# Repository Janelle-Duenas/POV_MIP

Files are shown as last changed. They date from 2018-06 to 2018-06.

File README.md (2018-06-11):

# POV_MIP
This project was developed by the UCSD Coordinated Robotics Laboratory

These folders contain all the files for the educational POV Mechanism that is mounted on the MIP.
The SolidWorks files folder is separated into plastic parts, eletromechanical parts and hardware.
Please download all these contents as displayed on the repository to retain the parts references for the main assembly.
The PCB Eagle files folder contains the schematic/board files.
The Code folder contains C files that use TI-RTOS.

For a more detail description of this project please see the following document

AIAA Confrence paper : link TBD

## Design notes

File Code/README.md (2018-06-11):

## Summary

This code has been modified from a samlpe TI code to connect to the custom made PCB,
and control the 16 RGB LEDS. The current example utilizes TI ADC API to get information from a hall sensor and then displays an image of a Pac-Man

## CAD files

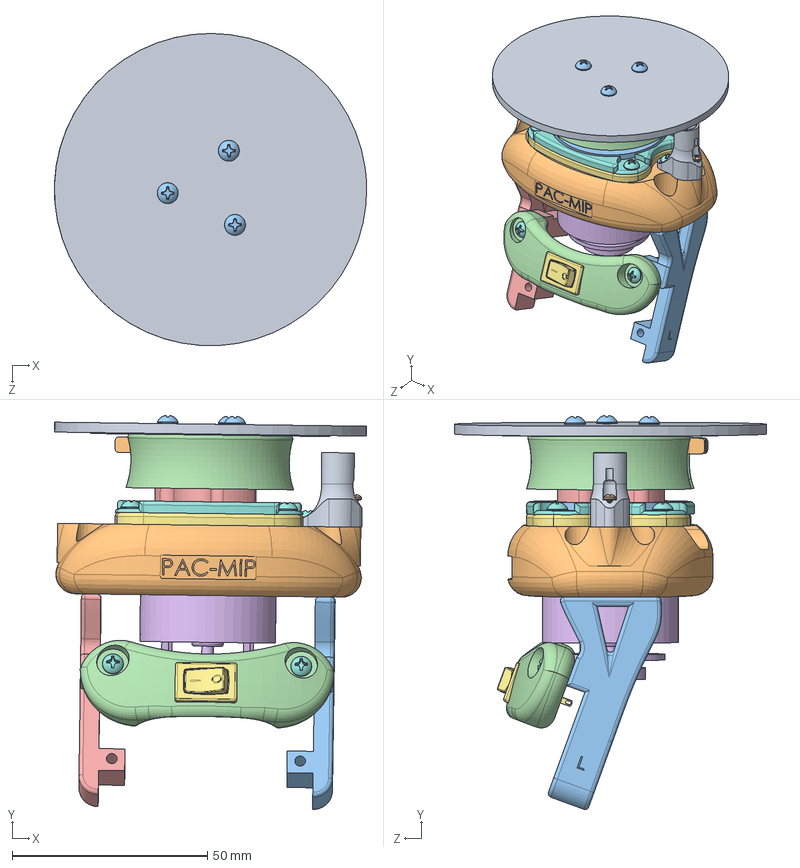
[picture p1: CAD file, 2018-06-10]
SolidWorks files/POV.SLDASM
80.0 x 100.9 x 79.9 mm
PCB disk
Main Frame
Coil x 2
Top Coil Mount
Motor Hub
Motor_pololu-37D-encoder
Motor Mount
Bottom Coil Mount
Magnet Stand
Wire Mount
Left Support
Switch Mount
Right Support
Magnet
Rocker Switch
90279A110_ZNC PLTD STL ROUND HEAD PHILLIP MACHINE SCREW x 7
90279A112_ZNC PLTD STL ROUND HEAD PHILLIP MACHINE SCREW x 4
92000A006_18-8 SS METRIC PAN HEAD PHIL MACHINE SCREW
90279A103_ZNC PLTD STL ROUND HEAD PHILLIP MACHINE SCREW x 3

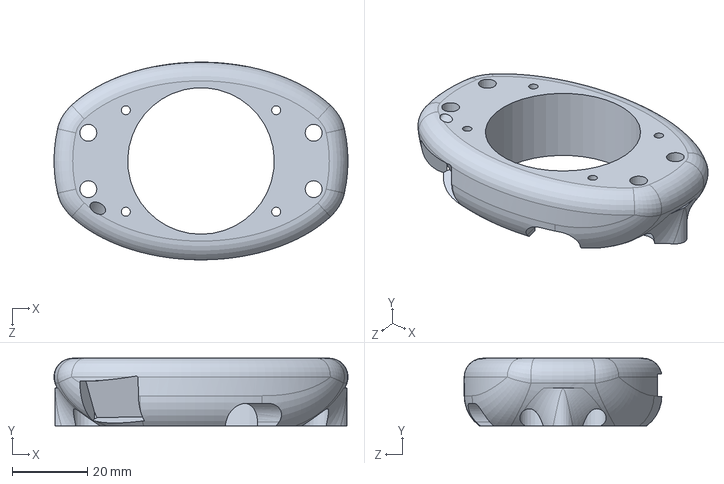
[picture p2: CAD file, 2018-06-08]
SolidWorks files/plastic parts/3D-printed/Main Frame.SLDPRT
78.2 x 18.0 x 52.6 mm

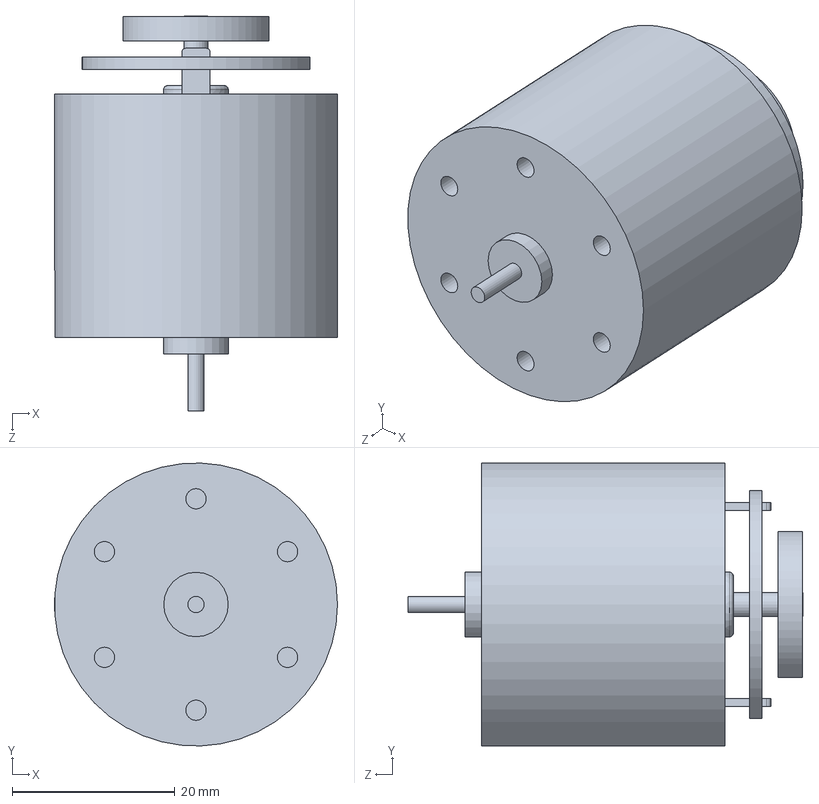
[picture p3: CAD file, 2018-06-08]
SolidWorks files/ElectroMechanical parts/Motor_pololu-37D-encoder.SLDPRT
34.8 x 34.8 x 48.5 mm

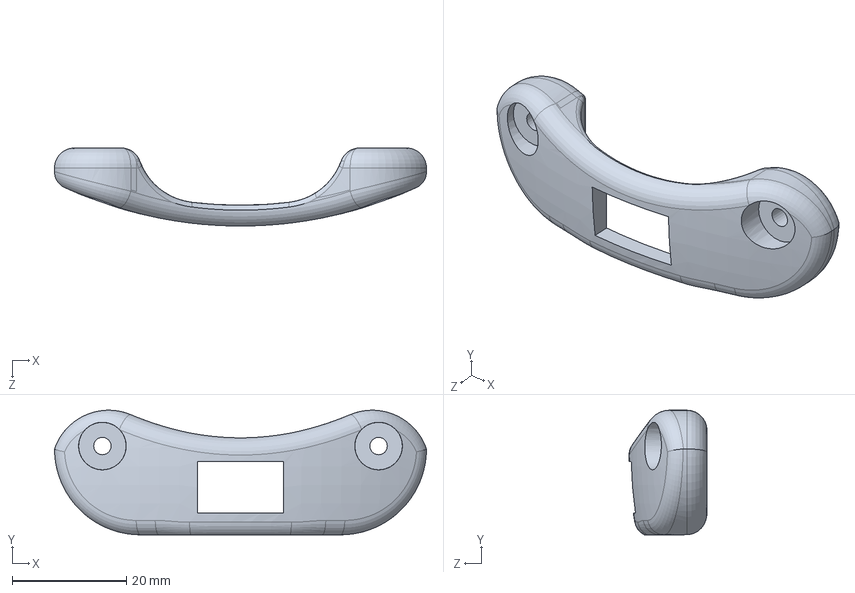
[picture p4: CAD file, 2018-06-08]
SolidWorks files/plastic parts/3D-printed/Switch Mount.SLDPRT
65.0 x 21.8 x 13.6 mm

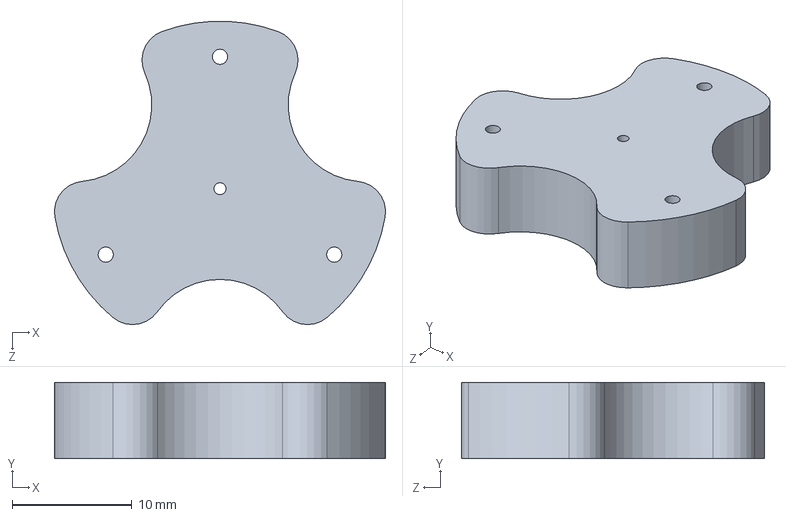
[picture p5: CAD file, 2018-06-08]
SolidWorks files/plastic parts/laser cut/Motor Hub.SLDPRT
27.6 x 6.35 x 25.3 mm

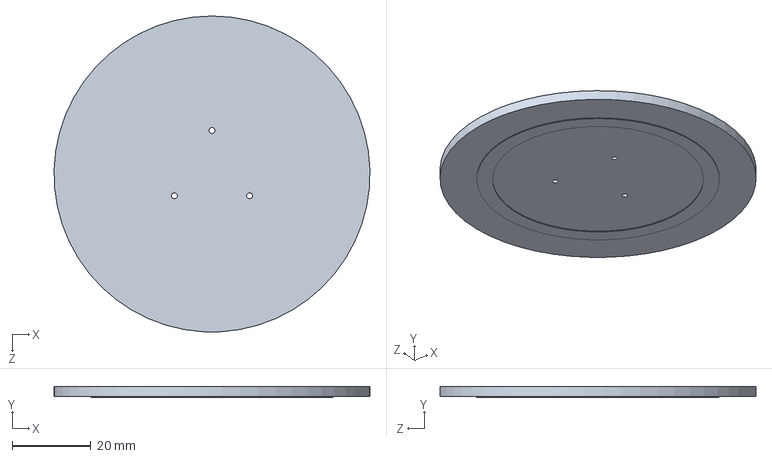
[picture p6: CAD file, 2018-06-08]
SolidWorks files/ElectroMechanical parts/PCB disk.SLDPRT
80.0 x 2.79 x 80.0 mm

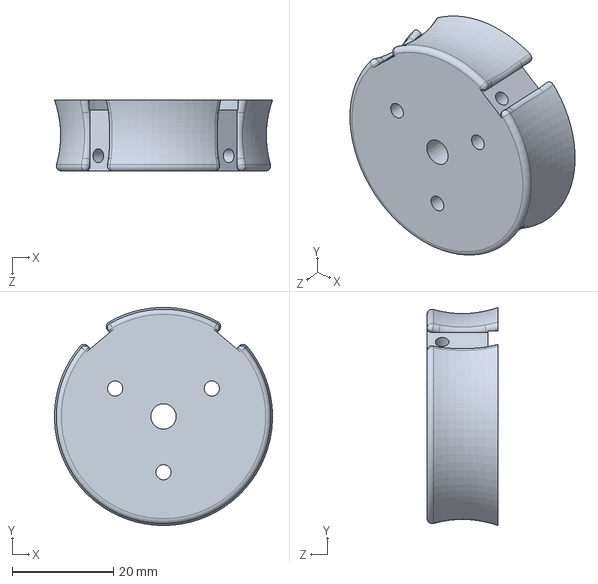
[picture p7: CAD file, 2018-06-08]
SolidWorks files/plastic parts/3D-printed/Top Coil Mount.SLDPRT
43.0 x 43.0 x 14.0 mm

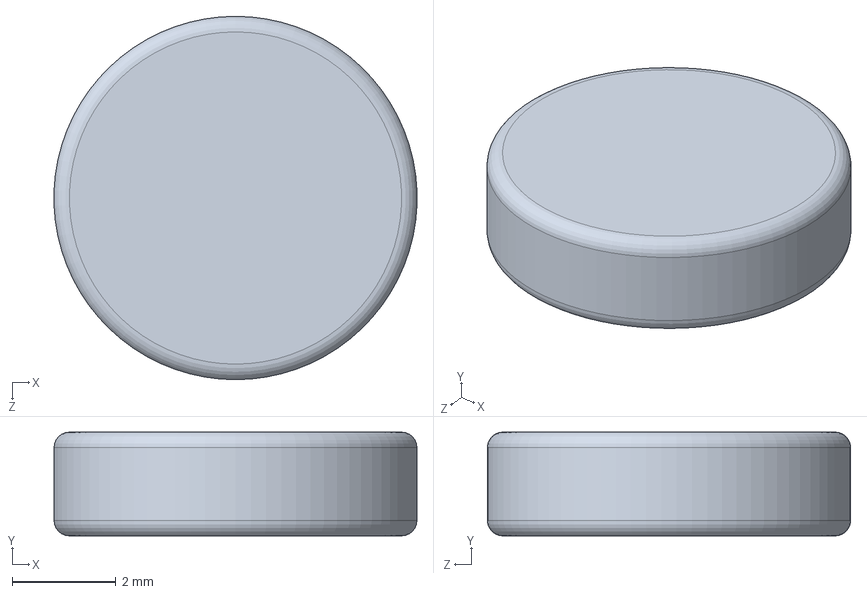
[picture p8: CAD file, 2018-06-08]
SolidWorks files/ElectroMechanical parts/Magnet.SLDPRT
6.99 x 2.00 x 7.00 mm

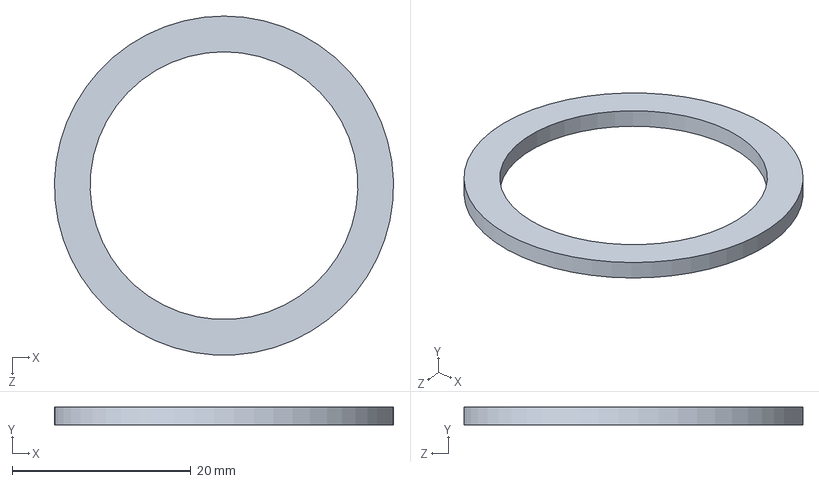
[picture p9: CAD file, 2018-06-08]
SolidWorks files/hardware/Coil.SLDPRT
38.0 x 2.00 x 38.0 mm

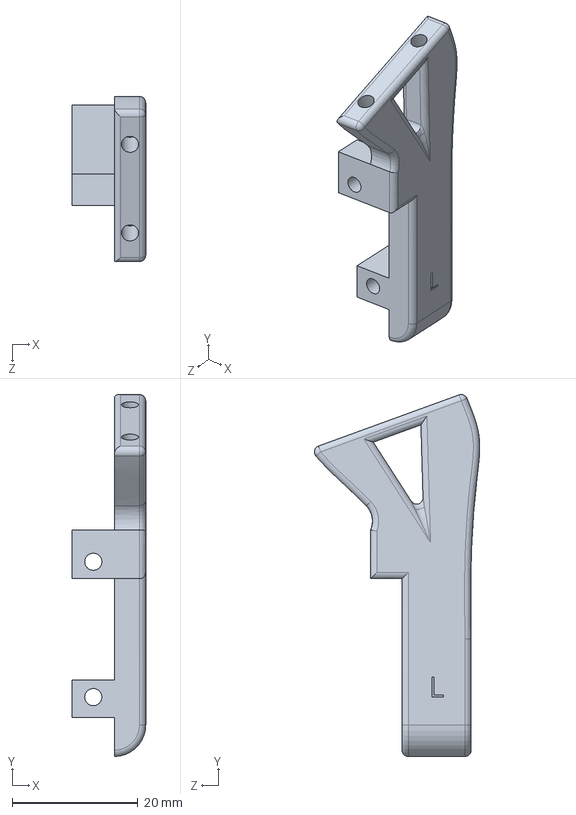
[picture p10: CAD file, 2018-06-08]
SolidWorks files/plastic parts/3D-printed/Left Support.SLDPRT
11.7 x 57.6 x 26.3 mm

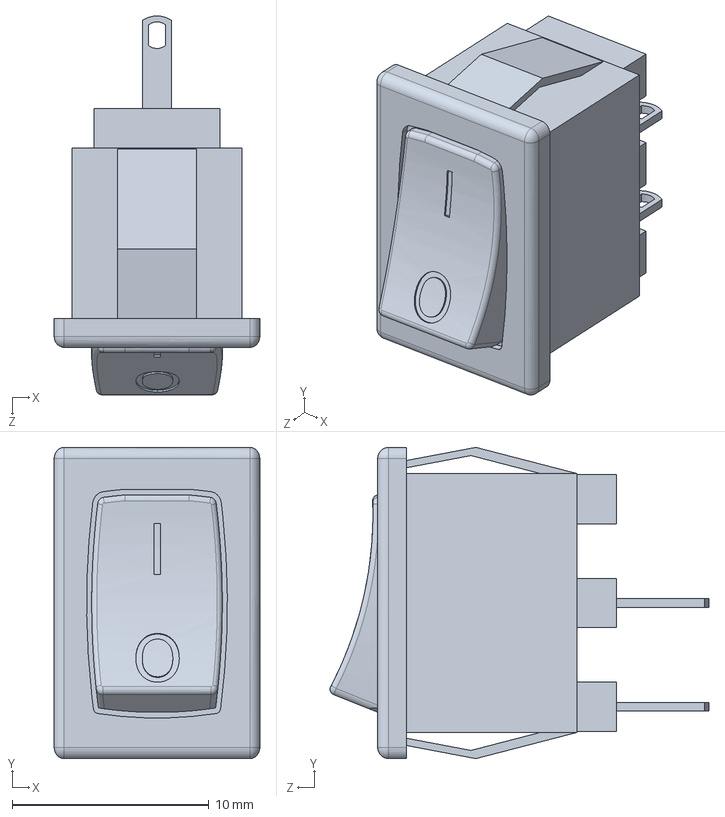
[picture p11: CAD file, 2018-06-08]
SolidWorks files/ElectroMechanical parts/Rocker Switch.SLDPRT
10.5 x 15.8 x 19.3 mm

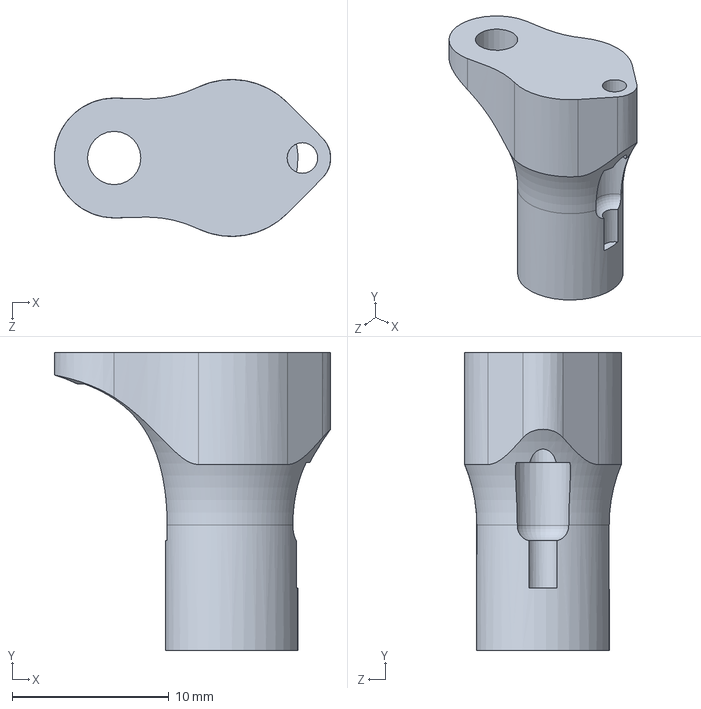
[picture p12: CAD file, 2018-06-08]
SolidWorks files/plastic parts/3D-printed/Magnet Stand.SLDPRT
17.6 x 19.0 x 10.00 mm

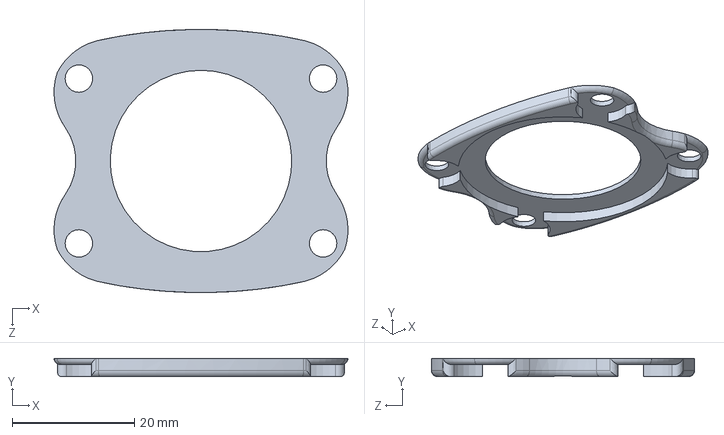
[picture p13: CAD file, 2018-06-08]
SolidWorks files/plastic parts/3D-printed/Bottom Coil Mount.SLDPRT
48.2 x 3.00 x 43.1 mm

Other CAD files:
Code/adcsinglechannel_CC2650_LAUNCHXL_TI_CC2650F128/src/sysbios/m3_TaskSupport_asm.obj
Code/adcsinglechannel_CC2650_LAUNCHXL_TI_CC2650F128/src/sysbios/m3_Hwi_asm.obj
Code/adcsinglechannel_CC2650_LAUNCHXL_TI_CC2650F128/src/sysbios/m3_IntrinsicsSupport_asm.obj
Code/adcsinglechannel_CC2650_LAUNCHXL_TI_CC2650F128/src/sysbios/m3_Hwi_asm_switch.obj
Code/adcsinglechannel_CC2650_LAUNCHXL_TI_CC2650F128/src/sysbios/rom_sysbios.obj
SolidWorks files/hardware/90279A103_ZNC PLTD STL ROUND HEAD PHILLIP MACHINE SCREW.SLDPRT
SolidWorks files/hardware/90279A110_ZNC PLTD STL ROUND HEAD PHILLIP MACHINE SCREW.SLDPRT
SolidWorks files/hardware/90279A112_ZNC PLTD STL ROUND HEAD PHILLIP MACHINE SCREW.SLDPRT
SolidWorks files/hardware/92000A006_18-8 SS METRIC PAN HEAD PHIL MACHINE SCREW.SLDPRT
SolidWorks files/plastic parts/3D-printed/Motor Mount.SLDPRT
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

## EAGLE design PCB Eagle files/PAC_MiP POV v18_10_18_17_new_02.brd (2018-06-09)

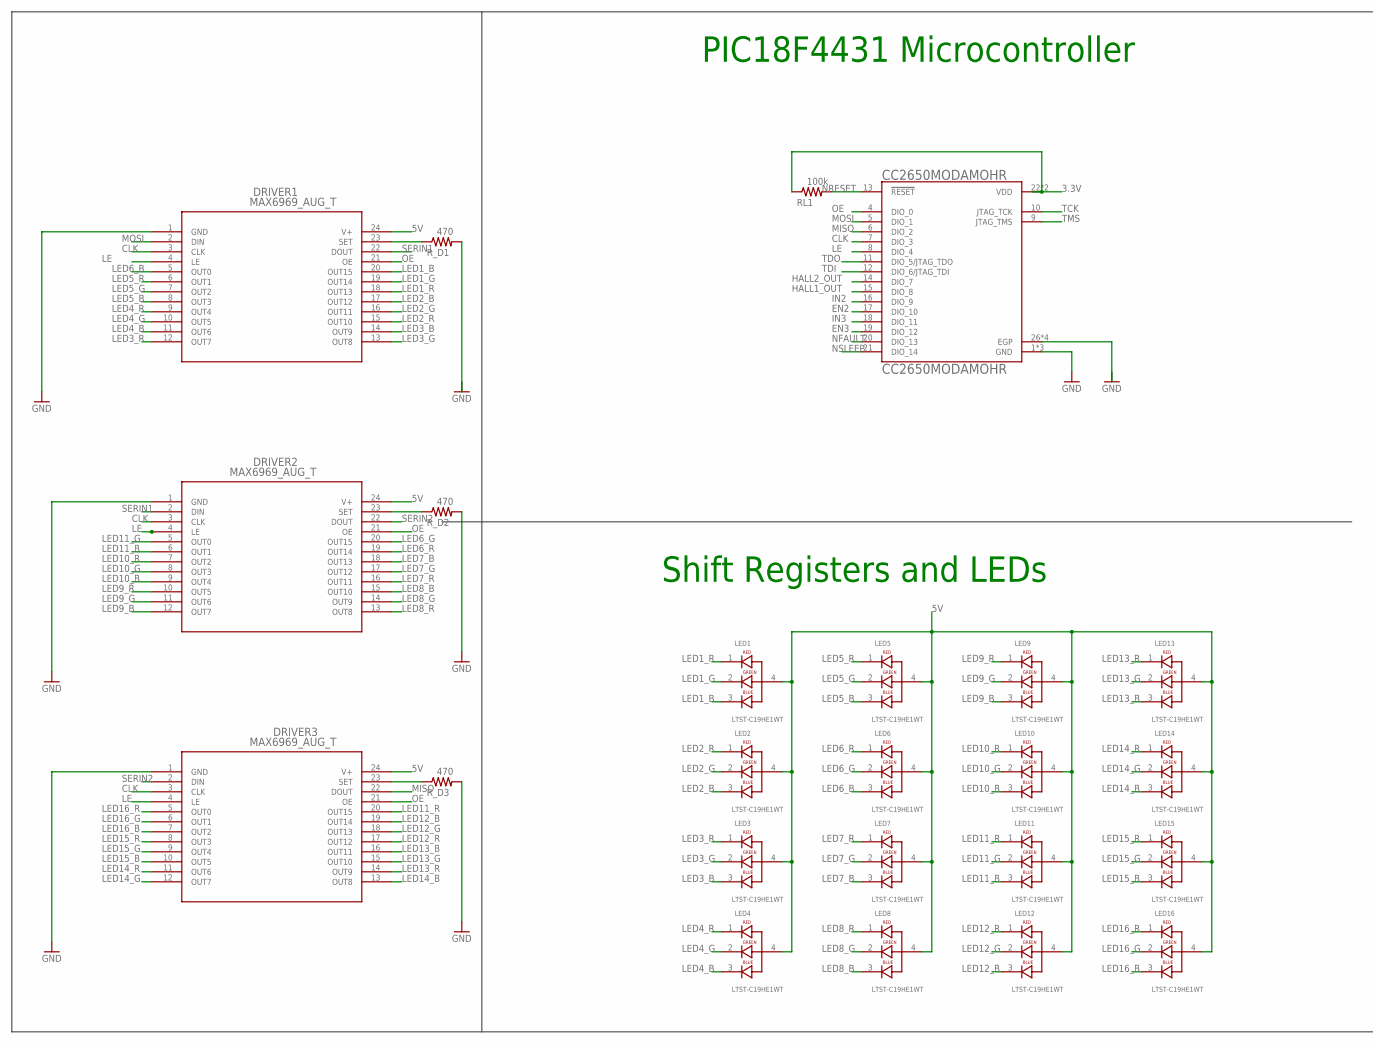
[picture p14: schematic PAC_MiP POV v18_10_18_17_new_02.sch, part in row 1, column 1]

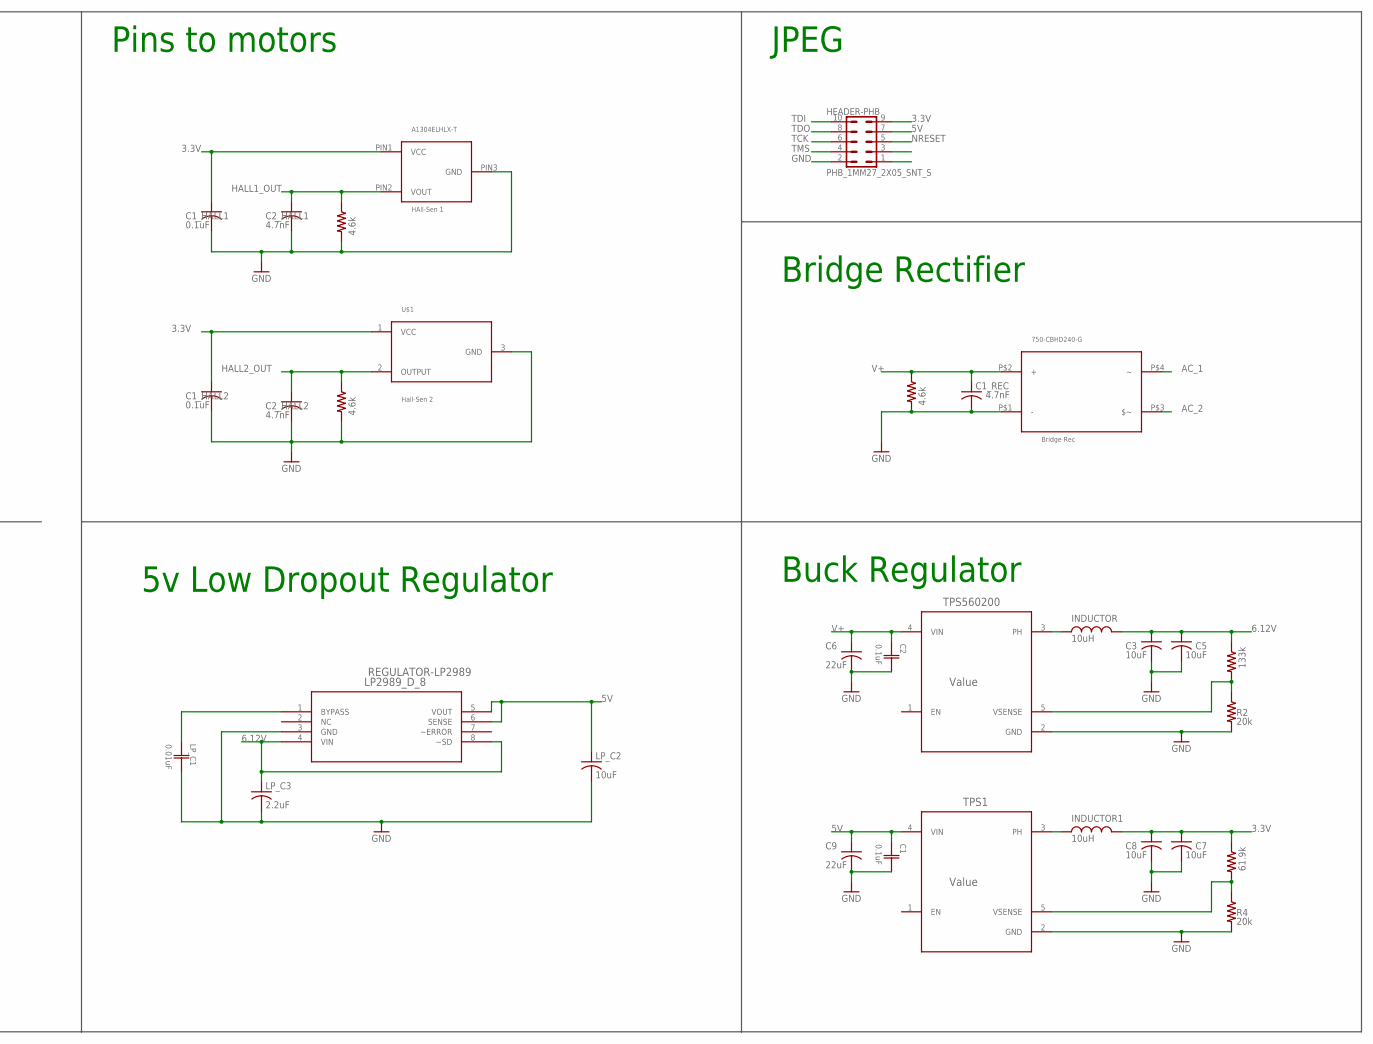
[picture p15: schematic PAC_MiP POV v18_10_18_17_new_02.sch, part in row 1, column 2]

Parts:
750-CBHD240-G: Bridge Rec; 750-CDBHD240-G
A1304ELHLX-T: HAll-Sen 1; A1304ELHLX-T
C1, C2: 0.1uF; 0508
C1_HALL1, C1_HALL2: 0.1uF; C0805
C1_REC, C2_HALL1, C2_HALL2: 4.7nF; C0805
C3, C5, C7, C8: 10uF; C0805
C6, C9: 22uF; C0805
CC2650MODAMOHR: CC2650MODAMOHR; XCVR_CC2650MODAMOHR
DRIVER1, DRIVER2, DRIVER3: MAX6969_AUG_T; 21_0066J_24
HEADER-PHB: PHB_1MM27_2X05_SNT_S; PHB_1MM27_2X05_SNT
INDUCTOR, INDUCTOR1: 10uH; CDPH4D19FNP100MC
LED1, LED2, LED3, LED4, LED5, LED6, LED7, LED8, LED9, LED10, LED11, LED12, LED13, LED14, LED15, LED16: LTST-C19HE1WT; LEDSC85P160X160X35-4N
LP_C1: 0.01uF; LLL18
LP_C2: 10uF; C0805
LP_C3: 2.2uF; C0805
R1: 133k; R0805
R1_HALL, R1_HALL2, R1_REC: 4.6k; R0805
R2, R4: 20k; R0805
R3: 61.9k; R0805
REGULATOR-LP2989: LP2989_D_8; M08A; PARTNUMBER LP2989AIM-18
RL1: 100k; R0805
R_D1, R_D2, R_D3: 470; R0805
TPS1, TPS560200: Value; DBV0005A_N
U$1: Hall-Sen 2; SOT-23-3

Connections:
3.3V: A1304ELHLX-T.PIN1 (VCC), C1_HALL1.1, C1_HALL2.1, C7.1, C8.1, CC2650MODAMOHR.22 (VDD), CC2650MODAMOHR.23 (VDD), HEADER-PHB.9, INDUCTOR1.P$2, R3.1, RL1.1, U$1.1 (VCC)
5V: C1.1, C9.1, DRIVER1.24 (V+), DRIVER2.24 (V+), DRIVER3.24 (V+), HEADER-PHB.7, LED1.4, LED2.4, LED3.4, LED4.4, LED5.4, LED6.4, LED7.4, LED8.4, LED9.4, LED10.4, LED11.4, LED12.4, LED13.4, LED14.4, LED15.4, LED16.4, LP_C2.1, REGULATOR-LP2989.5 (VOUT), REGULATOR-LP2989.6 (SENSE), TPS1.4 (VIN)
6.12V: C3.1, C5.1, INDUCTOR.P$2, LP_C3.1, R1.1, REGULATOR-LP2989.4 (VIN), REGULATOR-LP2989.8 (~SD)
AC_1: 750-CBHD240-G.P$4
AC_2: 750-CBHD240-G.P$3 ($~)
CLK: CC2650MODAMOHR.7 (DIO_3), DRIVER1.3 (CLK), DRIVER2.3 (CLK), DRIVER3.3 (CLK)
EN2: CC2650MODAMOHR.17 (DIO_10)
EN3: CC2650MODAMOHR.19 (DIO_12)
GND: 750-CBHD240-G.P$1 (-), A1304ELHLX-T.PIN3 (GND), C1.2, C1_HALL1.2, C1_HALL2.2, C1_REC.2, C2.2, C2_HALL1.2, C2_HALL2.2, C3.2, C5.2, C6.2, C7.2, C8.2, C9.2, CC2650MODAMOHR.1 (GND), CC2650MODAMOHR.3 (GND), CC2650MODAMOHR.25 (GND), CC2650MODAMOHR.26 (EGP), CC2650MODAMOHR.27 (EGP), CC2650MODAMOHR.28 (EGP), CC2650MODAMOHR.29 (EGP), DRIVER1.1 (GND), DRIVER2.1 (GND), DRIVER3.1 (GND), HEADER-PHB.2, LP_C1.2, LP_C2.2, LP_C3.2, R1_HALL.2, R1_HALL2.2, R1_REC.2, R2.2, R4.2, REGULATOR-LP2989.3 (GND), R_D2.2, R_D3.2, TPS1.2 (GND), TPS560200.2 (GND), U$1.3 (GND)
HALL1_OUT: A1304ELHLX-T.PIN2 (VOUT), C2_HALL1.1, CC2650MODAMOHR.15 (DIO_8), R1_HALL.1
HALL2_OUT: C2_HALL2.1, CC2650MODAMOHR.14 (DIO_7), R1_HALL2.1, U$1.2 (OUTPUT)
IN2: CC2650MODAMOHR.16 (DIO_9)
IN3: CC2650MODAMOHR.18 (DIO_11)
LE: CC2650MODAMOHR.8 (DIO_4), DRIVER1.4 (LE), DRIVER2.4 (LE), DRIVER3.4 (LE)
LED1_B: DRIVER1.20 (OUT15), LED1.3
LED1_G: DRIVER1.19 (OUT14), LED1.2
LED1_R: DRIVER1.18 (OUT13), LED1.1
LED2_B: DRIVER1.17 (OUT12), LED2.3
LED2_G: DRIVER1.16 (OUT11), LED2.2
LED2_R: DRIVER1.15 (OUT10), LED2.1
LED3_B: DRIVER1.14 (OUT9), LED3.3
LED3_G: DRIVER1.13 (OUT8), LED3.2
LED3_R: DRIVER1.12 (OUT7), LED3.1
LED4_B: DRIVER1.11 (OUT6), LED4.3
LED4_G: DRIVER1.10 (OUT5), LED4.2
LED4_R: DRIVER1.9 (OUT4), LED4.1
LED5_B: DRIVER1.8 (OUT3), LED5.3
LED5_G: DRIVER1.7 (OUT2), LED5.2
LED5_R: DRIVER1.6 (OUT1), LED5.1
LED6_B: DRIVER1.5 (OUT0), LED6.3
LED6_G: DRIVER2.20 (OUT15), LED6.2
LED6_R: DRIVER2.19 (OUT14), LED6.1
LED7_B: DRIVER2.18 (OUT13), LED7.3
LED7_G: DRIVER2.17 (OUT12), LED7.2
LED7_R: DRIVER2.16 (OUT11), LED7.1
LED8_B: DRIVER2.15 (OUT10), LED8.3
LED8_G: DRIVER2.14 (OUT9), LED8.2
LED8_R: DRIVER2.13 (OUT8), LED8.1
LED9_B: DRIVER2.12 (OUT7), LED9.3
LED9_G: DRIVER2.11 (OUT6), LED9.2
LED9_R: DRIVER2.10 (OUT5), LED9.1
LED10_B: DRIVER2.9 (OUT4), LED10.3
LED10_G: DRIVER2.8 (OUT3), LED10.2
LED10_R: DRIVER2.7 (OUT2), LED10.1
LED11_B: DRIVER2.6 (OUT1), LED11.3
LED11_G: DRIVER2.5 (OUT0), LED11.2
LED11_R: DRIVER3.20 (OUT15), LED11.1
LED12_B: DRIVER3.19 (OUT14), LED12.3
LED12_G: DRIVER3.18 (OUT13), LED12.2
LED12_R: DRIVER3.17 (OUT12), LED12.1
LED13_B: DRIVER3.16 (OUT11), LED13.3
LED13_G: DRIVER3.15 (OUT10), LED13.2
LED13_R: DRIVER3.14 (OUT9), LED13.1
LED14_B: DRIVER3.13 (OUT8), LED14.3
LED14_G: DRIVER3.12 (OUT7), LED14.2
LED14_R: DRIVER3.11 (OUT6), LED14.1
LED15_B: DRIVER3.10 (OUT5), LED15.3
LED15_G: DRIVER3.9 (OUT4), LED15.2
LED15_R: DRIVER3.8 (OUT3), LED15.1
LED16_B: DRIVER3.7 (OUT2), LED16.3
LED16_G: DRIVER3.6 (OUT1), LED16.2
LED16_R: DRIVER3.5 (OUT0), LED16.1
MISO: CC2650MODAMOHR.6 (DIO_2), DRIVER3.22 (DOUT)
MOSI: CC2650MODAMOHR.5 (DIO_1), DRIVER1.2 (DIN)
unnamed: INDUCTOR.P$1, TPS560200.3 (PH)
unnamed: DRIVER3.23 (SET), R_D3.1
unnamed: R1.2, R2.1, TPS560200.5 (VSENSE)
unnamed: R3.2, R4.1, TPS1.5 (VSENSE)
unnamed: INDUCTOR1.P$1, TPS1.3 (PH)
unnamed: DRIVER2.23 (SET), R_D2.1
unnamed: DRIVER1.23 (SET), R_D1.1
unnamed: LP_C1.1, REGULATOR-LP2989.1 (BYPASS)
NFAULT: CC2650MODAMOHR.20 (DIO_13)
NRESET: CC2650MODAMOHR.13 (!RESET), HEADER-PHB.5, RL1.2
NSLEEP: CC2650MODAMOHR.21 (DIO_14)
OE: CC2650MODAMOHR.4 (DIO_0), DRIVER1.21 (OE), DRIVER2.21 (OE), DRIVER3.21 (OE)
SERIN1: DRIVER1.22 (DOUT), DRIVER2.2 (DIN)
SERIN2: DRIVER2.22 (DOUT), DRIVER3.2 (DIN)
TCK: CC2650MODAMOHR.10 (JTAG_TCK), HEADER-PHB.6
TDI: CC2650MODAMOHR.12 (DIO_6/JTAG_TDI), HEADER-PHB.10
TDO: CC2650MODAMOHR.11 (DIO_5/JTAG_TDO), HEADER-PHB.8
TMS: CC2650MODAMOHR.9 (JTAG_TMS), HEADER-PHB.4
V+: 750-CBHD240-G.P$2 (+), C1_REC.1, C2.1, C6.1, R1_REC.1, TPS560200.4 (VIN)

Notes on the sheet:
Pins to motors
Buck Regulator
Bridge Rectifier
PIC18F4431 Microcontroller
JPEG
Shift Registers and LEDs
5v Low Dropout Regulator

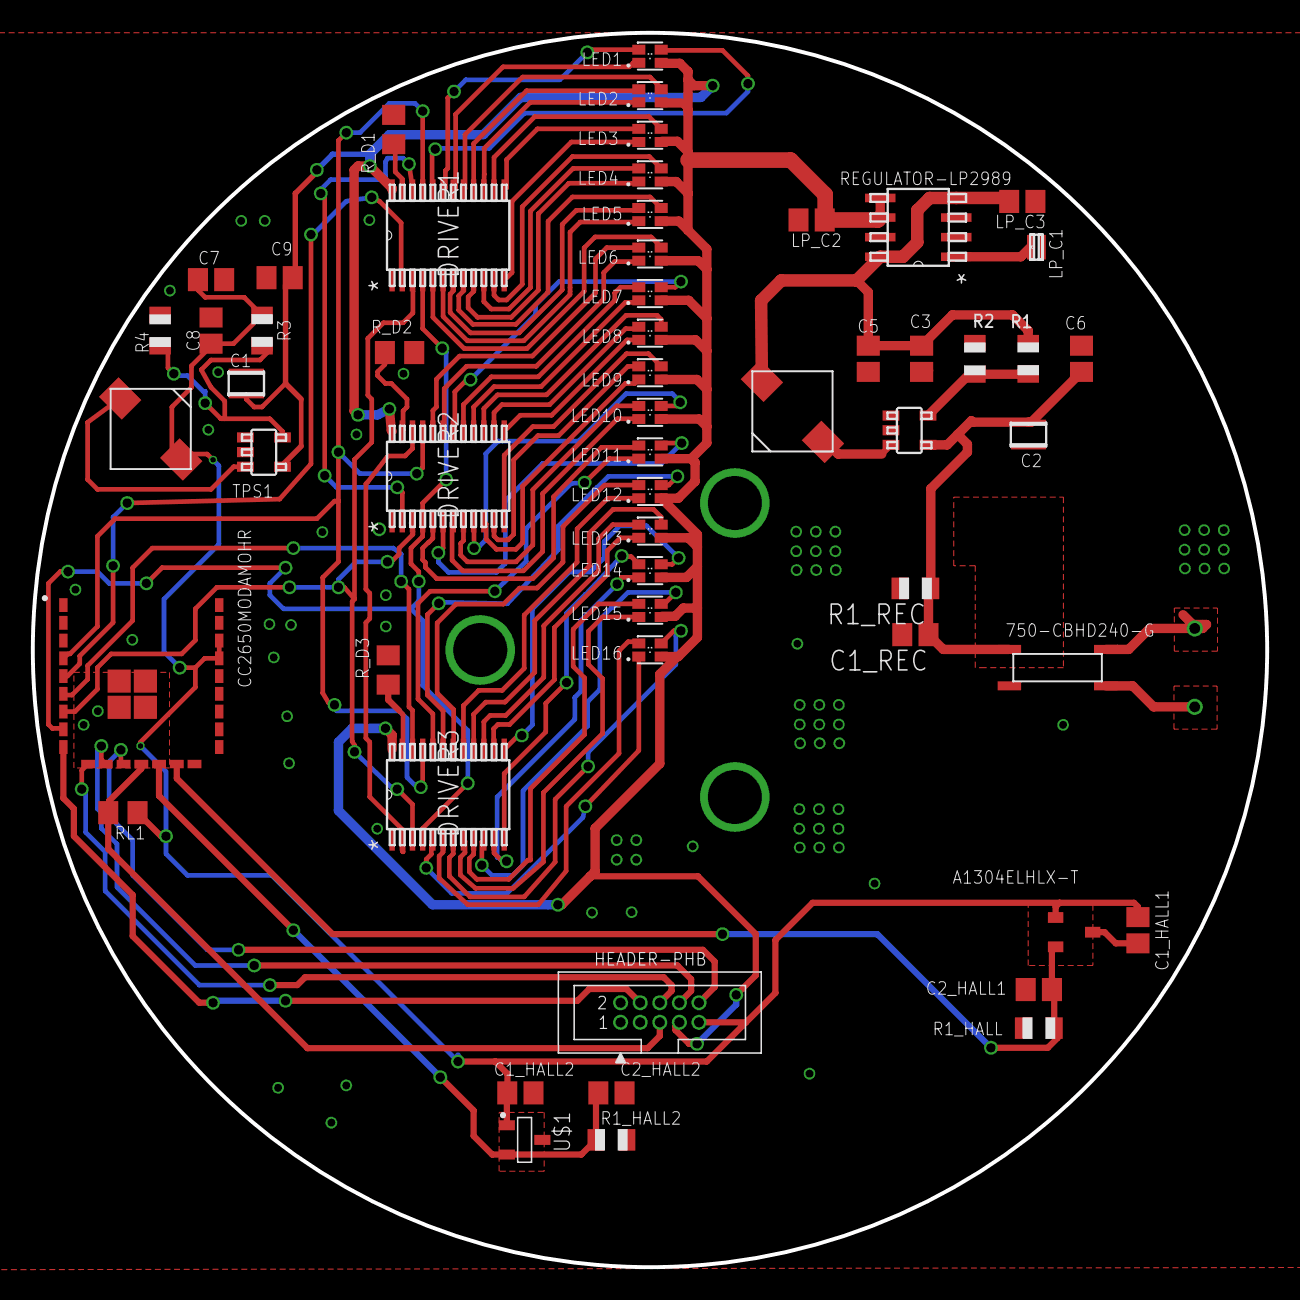
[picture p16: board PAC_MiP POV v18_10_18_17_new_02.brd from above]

Board: 4 copper layers, 80.0 x 80.0 mm, 56 parts (0 on the bottom side), 75 nets.

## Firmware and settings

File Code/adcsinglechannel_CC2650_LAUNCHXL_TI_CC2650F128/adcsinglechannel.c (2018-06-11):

/*
 * Copyright (c) 2016, Texas Instruments Incorporated
 * All rights reserved.
 *
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
 * *  Redistributions of source code must retain the above copyright
 *    notice, this list of conditions and the following disclaimer.
 *
 * *  Redistributions in binary form must reproduce the above copyright
 *    notice, this list of conditions and the following disclaimer in the
 *    documentation and/or other materials provided with the distribution.
 *
 * *  Neither the name of Texas Instruments Incorporated nor the names of
 *    its contributors may be used to endorse or promote products derived
 *    from this software without specific prior written permission.
 *
 * THIS SOFTWARE IS PROVIDED BY THE COPYRIGHT HOLDERS AND CONTRIBUTORS "AS IS"
 * AND ANY EXPRESS OR IMPLIED WARRANTIES, INCLUDING, BUT NOT LIMITED TO,
 * THE IMPLIED WARRANTIES OF MERCHANTABILITY AND FITNESS FOR A PARTICULAR
 * PURPOSE ARE DISCLAIMED. IN NO EVENT SHALL THE COPYRIGHT OWNER OR
 * CONTRIBUTORS BE LIABLE FOR ANY DIRECT, INDIRECT, INCIDENTAL, SPECIAL,
 * EXEMPLARY, OR CONSEQUENTIAL DAMAGES (INCLUDING, BUT NOT LIMITED TO,
 * PROCUREMENT OF SUBSTITUTE GOODS OR SERVICES; LOSS OF USE, DATA, OR PROFITS;
 * OR BUSINESS INTERRUPTION) HOWEVER CAUSED AND ON ANY THEORY OF LIABILITY,
 * WHETHER IN CONTRACT, STRICT LIABILITY, OR TORT (INCLUDING NEGLIGENCE OR
 * OTHERWISE) ARISING IN ANY WAY OUT OF THE USE OF THIS SOFTWARE,
 * EVEN IF ADVISED OF THE POSSIBILITY OF SUCH DAMAGE.
 */

/*
 * %%%%%%%%%%%%%%%%%%%%%%%%%%%%%%%%%%%%%%%%%%%%%%%%%%%%%%%%%%%%%%%%%%%%%%%%%%%%%%%%%%%%%%%%%%%%%%%%%%%%%%%%%%%%
 * * READ ME!
 *
 * This code has been modified from TI adcsinglechannel_CC2650_LAUNCH_TI_CC2650F128
 * although the name has been kept to be the side, for comparison, this code connects to the
 * PCB created by the Coordinated Robotics Laboratory found at the link https://github.com/Janelle-Duenas/POV_MIP
 * The current code will display a PacMan
 *
 * %%%%%%%%%%%%%%%%%%%%%%%%%%%%%%%%%%%%%%%%%%%%%%%%%%%%%%%%%%%%%%%%%%%%%%%%%%%%%%%%%%%%%%%%%%%%%%%%%%%%%%%%%%%%%%

 */


/*
 *  ======== adcsinglechannel.c ========
 */
/* XDCtools Header files*/
#include <stdio.h>
#include <xdc/std.h>
#include <xdc/runtime/System.h>

//uses this for usleep
//#include <unistd.h>

/* BIOS Header files */
#include <ti/sysbios/BIOS.h>
#include <ti/sysbios/knl/Task.h>

/* Driver Header files */
#include <ti/drivers/ADC.h>
#include <ti/drivers/PIN.h>
#include <time.h>

#include <ti/drivers/pin/PINCC26XX.h>///janelle added this
#if defined(CC2650DK_7ID) || defined(CC1310DK_7XD)
#include <ti/drivers/PIN.h>

#include <ti/drivers/pin/PINCC26XX.h>///janelle added this
#endif

volatile uint32_t i,j;

/*
 *  ======== Pin set-up ========
 */

PIN_Config ledPinTable[] = {

    IOID_0 | PIN_GPIO_OUTPUT_EN | PIN_GPIO_LOW | PIN_PUSHPULL | PIN_DRVSTR_MAX,        //OE
    IOID_1 | PIN_GPIO_OUTPUT_EN | PIN_GPIO_LOW | PIN_PUSHPULL | PIN_DRVSTR_MAX,        //MOSI(DIN)
    IOID_3 | PIN_GPIO_OUTPUT_EN | PIN_GPIO_LOW | PIN_PUSHPULL | PIN_DRVSTR_MAX,        //CLK
    IOID_4 | PIN_GPIO_OUTPUT_EN | PIN_GPIO_HIGH | PIN_PUSHPULL | PIN_DRVSTR_MAX,        //LE


   // IOID_7 | PIN_GPIO_OUTPUT_EN | PIN_GPIO_LOW | PIN_PUSHPULL | PIN_DRVSTR_MAX,        //IN1
   // IOID_8 | PIN_GPIO_OUTPUT_EN | PIN_GPIO_LOW | PIN_PUSHPULL | PIN_DRVSTR_MAX,        //EN1
    IOID_9 | PIN_GPIO_OUTPUT_EN | PIN_GPIO_LOW | PIN_PUSHPULL | PIN_DRVSTR_MAX,        //IN2
    IOID_10 | PIN_GPIO_OUTPUT_EN | PIN_GPIO_LOW | PIN_PUSHPULL | PIN_DRVSTR_MAX,       //EN2
    IOID_11 | PIN_GPIO_OUTPUT_EN | PIN_GPIO_LOW | PIN_PUSHPULL | PIN_DRVSTR_MAX,        //IN3
    IOID_12 | PIN_GPIO_OUTPUT_EN | PIN_GPIO_LOW | PIN_PUSHPULL | PIN_DRVSTR_MAX,        //EN3
    IOID_14 | PIN_GPIO_OUTPUT_EN | PIN_GPIO_LOW | PIN_PUSHPULL | PIN_DRVSTR_MAX,        //nsleep
    ///IOID_7 | PIN_INPUT_EN | PIN_PULLDOWN,  //analog pin
    ///IOID_8 | PIN_INPUT_EN | PIN_PULLDOWN,  //analog pin

    PIN_TERMINATE

};


static PIN_Handle ledPinHandle;
static PIN_State ledPinState;




/* Example/Board Header files */
#include "Board.h"

/* ADC sample count */
#define ADC_SAMPLE_COUNT  (300)

/*Task Specific defines */
#define TASKSTACKSIZE     (768)

Task_Struct task0Struct;
Char task0Stack[TASKSTACKSIZE];

Task_Struct task1Struct;
Char task1Stack[TASKSTACKSIZE];

/* ADC conversion result variables */
uint16_t adcValue0;
uint16_t adcValue_current;
uint16_t adcValue1[ADC_SAMPLE_COUNT];
//double adcValue1[ADC_SAMPLE_COUNT];
double Time[ADC_SAMPLE_COUNT];
    int r=3;
/*
 *  ======== taskFxn0 ========
 *  Open an ADC instance and get a sampling result from a one-shot conversion.
 */
Void taskFxn0(UArg arg0, UArg arg1)
{
    ADC_Handle   adc;
    ADC_Params   params;
    int_fast16_t res;

    ADC_Params_init(&params);
    adc = ADC_open(Board_ADC0, &params);

    if (adc == NULL) {
        System_abort("Error initializing ADC channel 0\n");
    }
    else {
       // System_printf("ADC channel 0 initialized\n");
    }

    /* Blocking mode conversion */
    res = ADC_convert(adc, &adcValue0);

    if (res == ADC_STATUS_SUCCESS) {
       System_printf("ADC channel 0 convert result: 0x%x\n", adcValue0);
    }
    else {
        System_printf("ADC channel 0 convert failed\n");
    }

    ADC_close(adc);


    System_flush();
}

/*
 *  ======== taskFxn1 ========
 *  Open a ADC handle and get a array of sampling results after
 *  calling several conversions.
 */
Void taskFxn1(UArg arg0, UArg arg1)
{
    uint16_t     i=0;
    ADC_Handle   adc;
    ADC_Params   params;
    int_fast16_t res;

    ADC_Params_init(&params);
    adc = ADC_open(Board_ADC0, &params);

    if (adc == NULL) {
        System_abort("Error initializing ADC channel 1\n");
    }
    else {
      //  System_printf("ADC channel 1 initialized\n");
    }
////////////////////////////////////////////////////////////////////////////
   /*for (i = 0; i < ADC_SAMPLE_COUNT; i++) {
     //while(true){
        //res = ADC_convert(adc, &adcValue1[i]);
       res = ADC_convert(adc, &adcValue_current);

       if(1<ADC_SAMPLE_COUNT){
       adcValue1[i]=adcValue_current;
       time_t x=time(0);
        Time[i]=x;
       }
        //adcValue1[i]=hextoint(adcValue1[i]);

        if (res == ADC_STATUS_SUCCESS) {

        //  System_printf("ADC channel 1 convert result (%d): %d\n", i,//0x%x
           // adcValue1[i]);
        }
        else {
           // System_printf("ADC channel 1 convert failed (%d)\n", i);
            System_printf("ADC channel 1 convert failed\n");
        }

        if(adcValue_current>2250){//hexacecimal for 2250 or 2.25 V
           PIN_setOutputValue(ledPinHandle, IOID_0, Board_LED_OFF );    //OE TO TURN OF LE
           // printf("should be on\n");
           // printf("on");
           // printf("%d\n",adcValue1[i]);

        }
        else{
            PIN_setOutputValue(ledPinHandle, IOID_0, Board_LED_ON );    //OE TO TURN OF LE
          //  printf("should be off\n");
            //printf("off");
            //printf("%d\n",adcValue1[i]);

        }

        //i=i+1;*/

    /////////////////////////////////////////////////////////////////////////////////////////////////////////////////////////

        while(true){
           //res = ADC_convert(adc, &adcValue1[i]);
           res = ADC_convert(adc, &adcValue_current);
          // time_t x=time(0);
           //Time[i]=x;
           //adcValue1[i]=hextoint(adcValue1[i]);

           if (res == ADC_STATUS_SUCCESS) {

           //  System_printf("ADC channel 1 convert result (%d): %d\n", i,//0x%x
              // adcValue1[i]);
           }
           else {
              // System_printf("ADC channel 1 convert failed (%d)\n", i);
               System_printf("ADC channel 1 convert failed\n");
           }

           //if hall sensor passes over magnet turn on OE in turns it turns off LEDS
           //THEN DELAY

           ///This turns on leds
           if(adcValue_current<1850){//hexacecimal for 2200 or 2.2 V
              PIN_setOutputValue(ledPinHandle, IOID_0, Board_LED_OFF );    //OE TO TURN OF LE
             //printf("should be on\n");
              // printf("on");
             // printf("%d\n",adcValue_current);
              // sleep(100);
            //  Tsk_sleep();
             // TSK_sleep(500);

             // delay(10);

           }
           //This turns off leds
           else{
               PIN_setOutputValue(ledPinHandle, IOID_0, Board_LED_ON );    //OE TO TURN OF LE
            // printf("should be off\n");



               Task_sleep(200);
               //printf("off");
              //printf("%d\n",adcValue_current);

           }
           ////////////////////////////////////////////////////////////////////////////////////////////////////////////////

        System_flush();
    }
   /* if(i==500){
        System_printf("Done");
        System_flush();
    }*/


   ADC_close(adc);
}


/*
 *  ======== main ========
 */
int main(void)
{
    //struct tm *mytime = localtime(&now);

   // float k=0;
    Task_Params taskParams;

    /* Call board init functions */
    Board_initGeneral();
    Board_initADC();
// printf("hello, world\n");
    /* Create tasks */
/*
    Task_Params_init(&taskParams);
    taskParams.stackSize = TASKSTACKSIZE;
    taskParams.stack = &task0Stack;
    Task_construct(&task0Struct, (Task_FuncPtr)taskFxn0, &taskParams, NULL);
*/

    Task_Params_init(&taskParams);
    taskParams.stackSize = TASKSTACKSIZE;
    taskParams.stack = &task1Stack;
    Task_construct(&task1Struct, (Task_FuncPtr)taskFxn1, &taskParams, NULL);

    //allocating pins to handle
       ledPinHandle = PIN_open(&ledPinState, ledPinTable);


           if(!ledPinHandle) {

               System_abort("Error initializing board LED pins\n");

           }


           //PIN_setOutputValue(ledPinHandle, IOID_1, Board_LED_ON );    //MOSI,DIN
           PIN_setOutputValue(ledPinHandle, IOID_3, Board_LED_OFF );    //CLK
           PIN_setOutputValue(ledPinHandle, IOID_4, Board_LED_OFF );    //LE

           PIN_setOutputValue(ledPinHandle, IOID_0, Board_LED_ON );    //OE TO TURN OF LES (on turns off leds)

           int age[48]={1,0,1,1,0,1,1,0,1,1,0,1,1,0,1,1, //led 11R-16R
               1,1,0,1,1,0,1,1,0,1,1,0,1,1,0,1,
               //0,0,0,0,0,0,0,0,0,0,0,0,0,0,0,0};
               0,1,1,0,1,1,0,1,1,0,1,1,0,1,1,0};


           for ( j= 1; j<=48; j++){


/*           if(age[j]==1){
                 PIN_setOutputValue(ledPinHandle, IOID_1, Board_LED_ON);// change led color
                 PIN_setOutputValue(ledPinHandle, IOID_3, Board_LED_OFF );    // CLK = 0
                          //for(i=1000; i>0; i--);
                 PIN_setOutputValue(ledPinHandle, IOID_3, Board_LED_ON );
                          //for(i=1000; i>0; i--); // CLK = 1
                 }

            else{
                 PIN_setOutputValue(ledPinHandle, IOID_1, Board_LED_OFF);// change led color
                 PIN_setOutputValue(ledPinHandle, IOID_3, Board_LED_OFF );    // CLK = 0
                 //for(i=1000; i>0; i--);
                 PIN_setOutputValue(ledPinHandle, IOID_3, Board_LED_ON );
                 //for(i=1000; i>0; i--); // CLK = 1



           PIN_setOutputValue(ledPinHandle, IOID_4, Board_LED_ON );    //LE
           PIN_setOutputValue(ledPinHandle, IOID_4, Board_LED_OFF );    //LE

             }*/

          PIN_setOutputValue(ledPinHandle, IOID_1, Board_LED_OFF);// change led color
           PIN_setOutputValue(ledPinHandle, IOID_3, Board_LED_OFF );    // CLK = 0
           //for(i=1000; i>0; i--);
           PIN_setOutputValue(ledPinHandle, IOID_3, Board_LED_ON );
           //for(i=1000; i>0; i--); // CLK = 1

           PIN_setOutputValue(ledPinHandle, IOID_1, Board_LED_OFF);// change led color //ALL WORKING
           PIN_setOutputValue(ledPinHandle, IOID_3, Board_LED_OFF );    // CLK = 0
           //for(i=1000; i>0; i--);
           PIN_setOutputValue(ledPinHandle, IOID_3, Board_LED_ON );
           //for(i=1000; i>0; i--); // CLK = 1

           PIN_setOutputValue(ledPinHandle, IOID_1, Board_LED_ON);// change led color// ALL WOKING
           PIN_setOutputValue(ledPinHandle, IOID_3, Board_LED_OFF );    // CLK = 0
           //for(i=1000; i>0; i--);
           PIN_setOutputValue(ledPinHandle, IOID_3, Board_LED_ON );
           //for(i=1000; i>0; i--); // CLK = 1
           PIN_setOutputValue(ledPinHandle, IOID_4, Board_LED_ON );    //LE
           PIN_setOutputValue(ledPinHandle, IOID_4, Board_LED_OFF );    //LE


           }



// if the sensor is working the voltage should be higher than zero
           //therefore if value is greater than certain value
           //and code will go into loop turning off OE
           //WHICH turns ON leds

         /*  if(Board_ADC0>898){//hexacecimal for 2200 or 2.2 V
              PIN_setOutputValue(ledPinHandle, IOID_0, Board_LED_OFF );    //OE TO TURN OF LE
               printf("should be on\n");
           }
           else{
               PIN_setOutputValue(ledPinHandle, IOID_0, Board_LED_ON );    //OE TO TURN OF LE
               printf("should be off\n");
               printf("%d\n",Board_ADC0);
           }
*/



/*
 * The CC2650DK_7ID and CC1310DK_7XD measure an ambient light sensor in this example.
 * It is not powered by default to avoid high current consumption in other examples.
 * The code below turns on the power to the sensor.
 */
#if defined(CC2650DK_7ID) || defined(CC1310DK_7XD)
    PIN_State pinState;

    PIN_Config AlsPinTable[] =
    {
        Board_ALS_PWR    | PIN_GPIO_OUTPUT_EN | PIN_GPIO_HIGH    | PIN_PUSHPULL, /* Turn on ALS power */
        PIN_TERMINATE                                                            /* Terminate list */
    };

    /* Turn on the power to the ambient light sensor */
    PIN_open(&pinState, AlsPinTable);
#endif

   // System_printf("Starting the ADC Single Channel example\nSystem provider is "
       // "set to SysMin.  Halt the target to view any SysMin contents in ROV.\n");

    /* SysMin will only print to the console when you call flush or exit */
    System_flush();

    BIOS_start();

    return (0);
}

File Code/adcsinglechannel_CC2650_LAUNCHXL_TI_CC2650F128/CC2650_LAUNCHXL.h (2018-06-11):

/*
 * Copyright (c) 2015-2016, Texas Instruments Incorporated
 * All rights reserved.
 *
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
 * *  Redistributions of source code must retain the above copyright
 *    notice, this list of conditions and the following disclaimer.
 *
 * *  Redistributions in binary form must reproduce the above copyright
 *    notice, this list of conditions and the following disclaimer in the
 *    documentation and/or other materials provided with the distribution.
 *
 * *  Neither the name of Texas Instruments Incorporated nor the names of
 *    its contributors may be used to endorse or promote products derived
 *    from this software without specific prior written permission.
 *
 * THIS SOFTWARE IS PROVIDED BY THE COPYRIGHT HOLDERS AND CONTRIBUTORS "AS IS"
 * AND ANY EXPRESS OR IMPLIED WARRANTIES, INCLUDING, BUT NOT LIMITED TO,
 * THE IMPLIED WARRANTIES OF MERCHANTABILITY AND FITNESS FOR A PARTICULAR
 * PURPOSE ARE DISCLAIMED. IN NO EVENT SHALL THE COPYRIGHT OWNER OR
 * CONTRIBUTORS BE LIABLE FOR ANY DIRECT, INDIRECT, INCIDENTAL, SPECIAL,
 * EXEMPLARY, OR CONSEQUENTIAL DAMAGES (INCLUDING, BUT NOT LIMITED TO,
 * PROCUREMENT OF SUBSTITUTE GOODS OR SERVICES; LOSS OF USE, DATA, OR PROFITS;
 * OR BUSINESS INTERRUPTION) HOWEVER CAUSED AND ON ANY THEORY OF LIABILITY,
 * WHETHER IN CONTRACT, STRICT LIABILITY, OR TORT (INCLUDING NEGLIGENCE OR
 * OTHERWISE) ARISING IN ANY WAY OUT OF THE USE OF THIS SOFTWARE,
 * EVEN IF ADVISED OF THE POSSIBILITY OF SUCH DAMAGE.
 */
/** ============================================================================
 *  @file       CC2650_LAUNCHXL.h
 *
 *  @brief      CC2650 LaunchPad Board Specific header file.
 *
 *  NB! This is the board file for CC2650 LaunchPad PCB version 1.1
 *
 *  ============================================================================
 */
#ifndef __CC2650_LAUNCHXL_BOARD_H__
#define __CC2650_LAUNCHXL_BOARD_H__

#ifdef __cplusplus
extern "C" {
#endif

/** ============================================================================
 *  Includes
 *  ==========================================================================*/
#include <ti/drivers/PIN.h>
#include <driverlib/ioc.h>

/** ============================================================================
 *  Externs
 *  ==========================================================================*/
extern const PIN_Config BoardGpioInitTable[];

/** ============================================================================
 *  Defines
 *  ==========================================================================*/

/* Same RF Configuration as 7x7 EM */
#define CC2650EM_7ID
#define CC2650_LAUNCHXL

/* Mapping of pins to board signals using general board aliases
 *      <board signal alias>        <pin mapping>
 */

/* Discrete outputs */
#define Board_RLED                  IOID_6
#define Board_GLED                  IOID_7
#define Board_LED_ON                1
#define Board_LED_OFF               0

/* Discrete inputs */
#define Board_BTN1                  PIN_UNASSIGNED
#define Board_BTN2                  PIN_UNASSIGNED

/* UART Board */
#define Board_UART_RX               IOID_1          /* RXD  */
#define Board_UART_TX               IOID_0          /* TXD  */
#define Board_UART_CTS              IOID_19         /* CTS  */
#define Board_UART_RTS              IOID_18         /* RTS */

/* SPI Board */
#define Board_SPI0_MISO             IOID_12          /* RF1.20 */
#define Board_SPI0_MOSI             IOID_11          /* RF1.18 */
#define Board_SPI0_CLK              IOID_10         /* RF1.16 */
#define Board_SPI0_CSN              PIN_UNASSIGNED
#define Board_SPI1_MISO             PIN_UNASSIGNED
#define Board_SPI1_MOSI             PIN_UNASSIGNED
#define Board_SPI1_CLK              PIN_UNASSIGNED
#define Board_SPI1_CSN              PIN_UNASSIGNED

/* I2C */
#define Board_I2C0_SCL0             IOID_4
#define Board_I2C0_SDA0             IOID_5

/* SPI */
#define Board_SPI_FLASH_CS          IOID_9
#define Board_FLASH_CS_ON           0
#define Board_FLASH_CS_OFF          1

/* Booster pack generic */
#define Board_DIO0                  IOID_0
#define Board_DIO1_RFSW             IOID_1
#define Board_DIO12                 IOID_12
#define Board_DIO15                 IOID_15
#define Board_DIO16_TDO             IOID_5
#define Board_DIO17_TDI             IOID_6
#define Board_DIO21                 IOID_21
#define Board_DIO22                 IOID_22


//dio 8 hall 1 dio 7 hall 2
#define Board_DIO23_ANALOG          IOID_7//23
#define Board_DIO24_ANALOG          IOID_8
#define Board_DIO25_ANALOG          IOID_7
#define Board_DIO26_ANALOG          IOID_8
#define Board_DIO27_ANALOG          IOID_8
#define Board_DIO28_ANALOG          IOID_28
#define Board_DIO29_ANALOG          IOID_7
#define Board_DIO30_ANALOG          IOID_7

/* Booster pack LCD (430BOOST - Sharp96 Rev 1.1) */
#define Board_LCD_CS                IOID_24 // SPI chip select
#define Board_LCD_EXTCOMIN          IOID_12 // External COM inversion
#define Board_LCD_ENABLE            IOID_22 // LCD enable
#define Board_LCD_POWER             IOID_23 // LCD power control
#define Board_LCD_CS_ON             1
#define Board_LCD_CS_OFF            0

/* PWM outputs */
#define Board_PWMPIN0                       Board_RLED
#define Board_PWMPIN1                       Board_GLED
#define Board_PWMPIN2                       PIN_UNASSIGNED
#define Board_PWMPIN3                       PIN_UNASSIGNED
#define Board_PWMPIN4                       PIN_UNASSIGNED
#define Board_PWMPIN5                       PIN_UNASSIGNED
#define Board_PWMPIN6                       PIN_UNASSIGNED
#define Board_PWMPIN7                       PIN_UNASSIGNED
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

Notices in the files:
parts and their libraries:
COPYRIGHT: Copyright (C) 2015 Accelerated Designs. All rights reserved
